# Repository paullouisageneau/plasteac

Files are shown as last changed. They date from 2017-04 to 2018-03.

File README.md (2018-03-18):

# plasteac
A 3D-printed robotic dancing teapot

Refer to each subproject for license information.

Read my blog articles for more information:

https://chapelierfou.org/blog/plasteac-a-dancing-teapot.html

https://chapelierfou.org/blog/plasteac-enhancements.html

https://vimeo.com/214493309

Plasteac

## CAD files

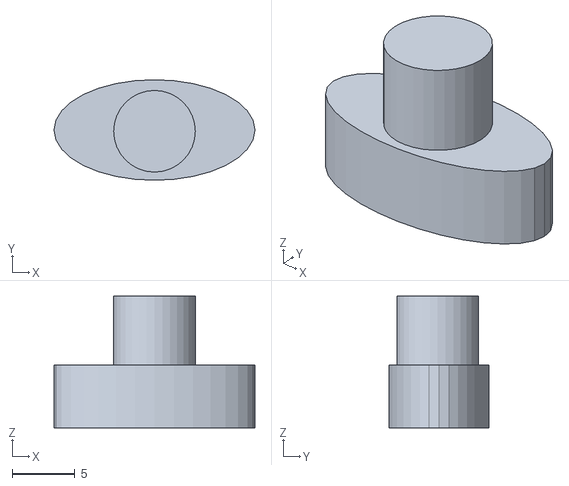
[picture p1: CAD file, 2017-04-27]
models/lid2_button.stl
16.0 x 8.00 x 10.5

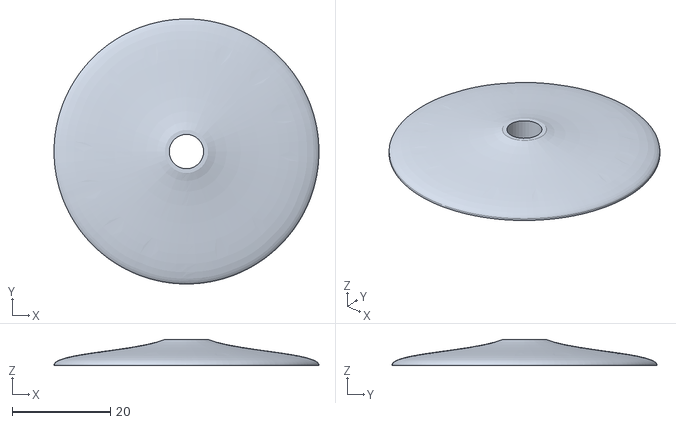
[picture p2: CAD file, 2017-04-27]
models/lid2_hole.stl
54.0 x 54.0 x 5.35

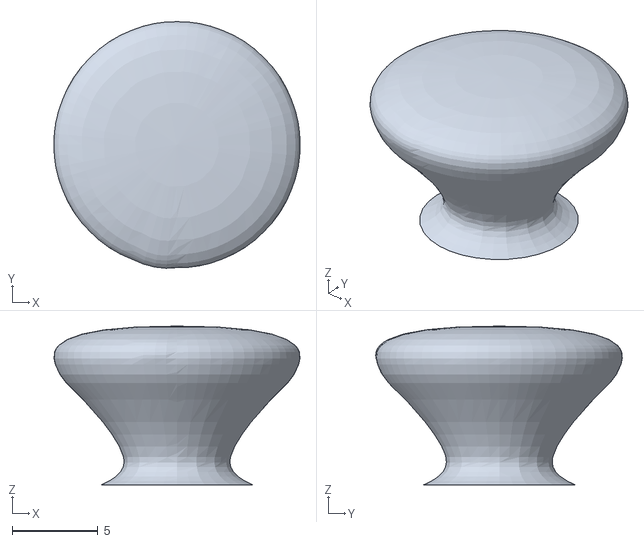
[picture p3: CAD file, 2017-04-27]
models/lid2_handle.stl
14.3 x 14.4 x 9.24

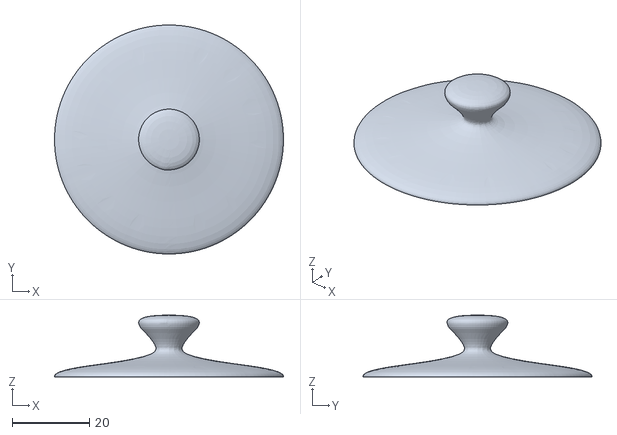
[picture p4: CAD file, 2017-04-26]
models/utah_lid.stl
59.4 x 59.4 x 16.0

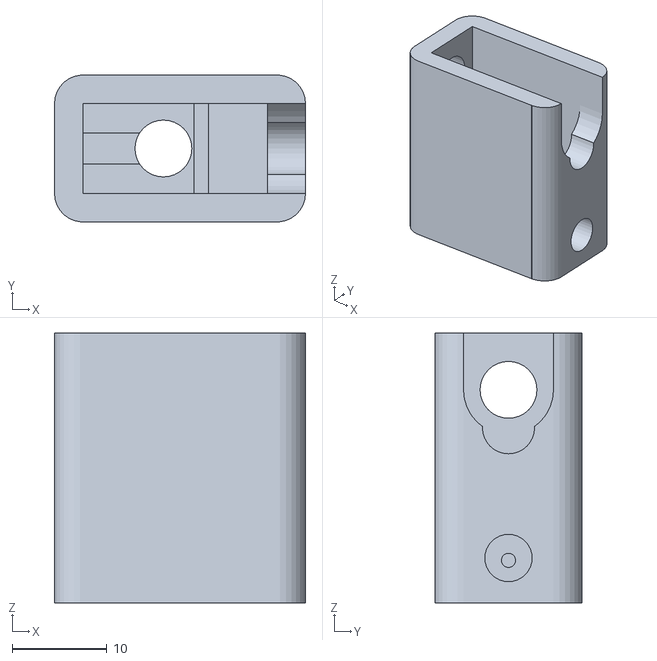
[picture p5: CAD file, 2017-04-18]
models/leg.stl
26.5 x 15.5 x 28.5

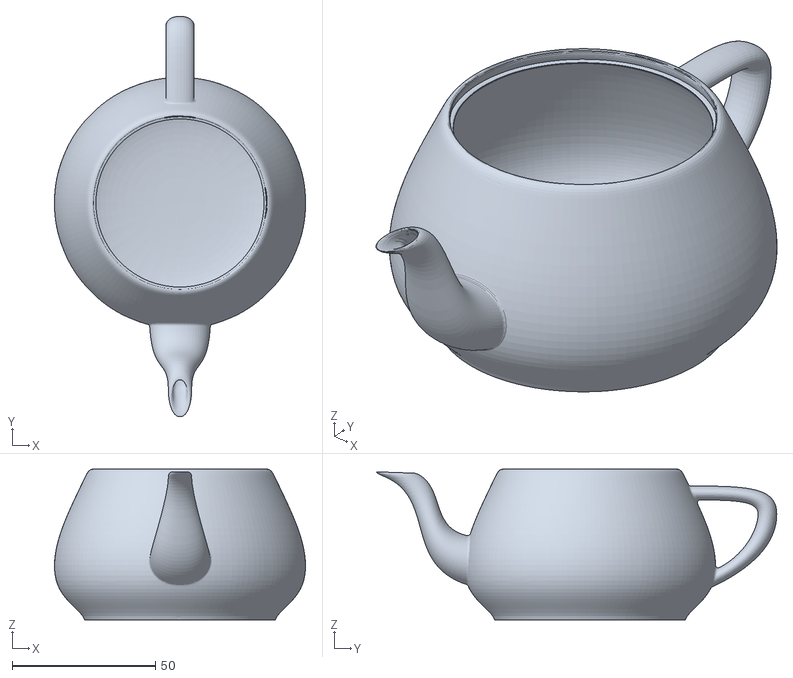
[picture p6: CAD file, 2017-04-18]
models/utah_teapot.stl
87.7 x 140.0 x 52.6

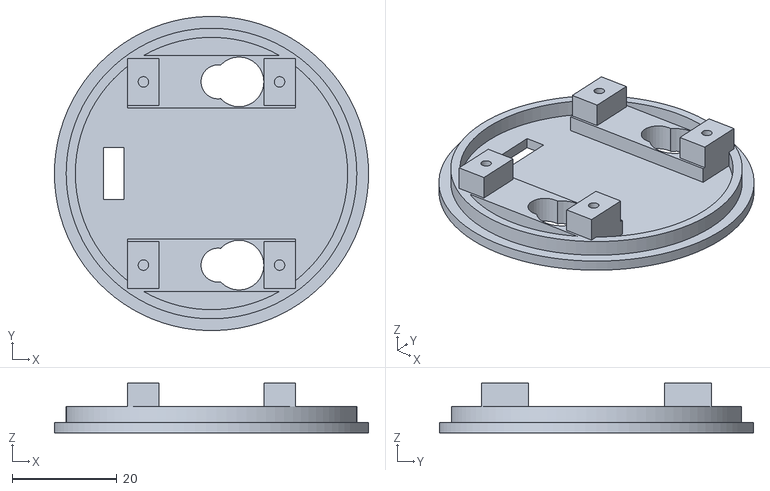
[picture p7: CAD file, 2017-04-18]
models/platform.stl
60.0 x 60.0 x 9.50

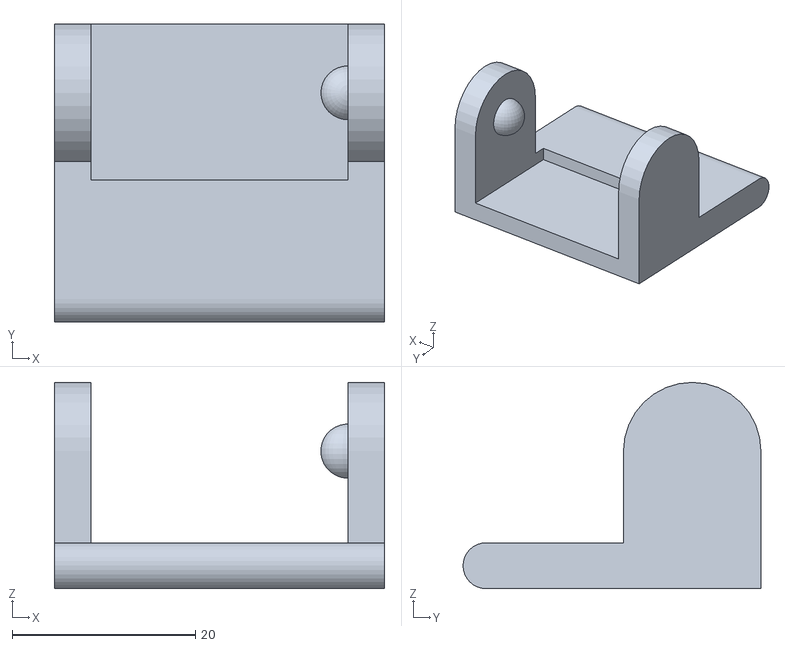
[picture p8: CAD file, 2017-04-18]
models/footr.stl
36.0 x 32.5 x 22.5

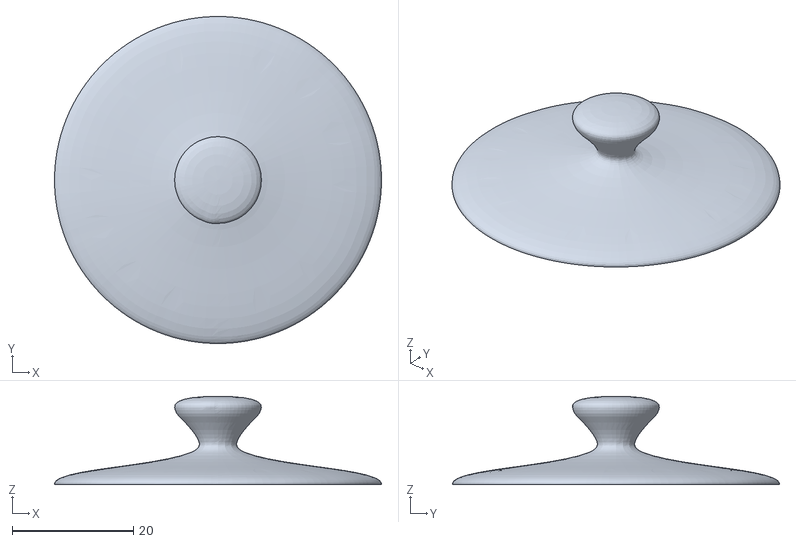
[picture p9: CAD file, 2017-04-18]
models/lid.stl
54.0 x 54.0 x 14.6

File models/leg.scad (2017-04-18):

/* 
 * Copyright (c) 2017 by Paul-Louis Ageneau
 *
 * This program is free software: you can redistribute it and/or modify
 * it under the terms of the GNU General Public License as published by
 * the Free Software Foundation, either version 3 of the License, or
 * (at your option) any later version.
 *
 * This program is distributed in the hope that it will be useful,
 * but WITHOUT ANY WARRANTY; without even the implied warranty of
 * MERCHANTABILITY or FITNESS FOR A PARTICULAR PURPOSE.  See the
 * GNU General Public License for more details.
 *
 * You should have received a copy of the GNU General Public License
 * along with this program.  If not, see <http://www.gnu.org/licenses/>.
 */

servo_height = 19 + 0.5;
servo_width  = 20 + 0.5;
servo_depth  =  9 + 0.5;
servo_side   =  6;
border = 3;
$fn = 32;

union() {
    difference() {
        rcube([servo_height, servo_depth, servo_width + servo_side] + [border*2+1, border*2, 2], border);
        translate([-0.5, 0, 2]) union() {
            cube([servo_height, servo_depth, servo_width + servo_side], center = true);
            translate([-servo_height/4, 0, 3-servo_width/2- 6]) cube([servo_height/2, 3.25, 3], center = true);
            translate([-1.25, 0, -servo_width/2]) cylinder(r = 3, h = 20, center = true);
            translate([0, 0, servo_width/2 - 4]) {
                translate([border+0.01, 0, servo_width/2]) cube([servo_height+border*2, servo_depth, servo_width], center = true);
                translate([servo_height/2, 0, -4]) rotate([0, 90, 0]) cylinder(r = 2.75, h = 10, center = true);
                translate([0, 0, 0]) rotate([0, 90, 0]) cylinder(r = 3, h = servo_height*2, center = true);
                translate([servo_height/2, 0, 0]) rotate([0, 90, 0]) cylinder(r = servo_depth/2, h = 10, center = true);
                translate([servo_height/2, 0, -18]) union() {
                    translate([0, 0, 0.25]) rotate([0, 90, 0]) cylinder(r = 2.5, h = 10, center = true);
                    translate([-3.75, 0, 0]) cube([7.5, servo_depth, servo_side], center = true);
                }
            }
        }
    }
    translate([servo_height/2-7.5, 0, 8 - 18]) difference() {
        cube([1.5, servo_depth, servo_side], center = true);
        translate([0, 0, 0.25]) rotate([0, 90, 0]) cylinder(r = 0.75, h = 10, center = true);
    }
}

module rcube(size, border) {
    union() {
        $fn = 30;
        cube(size = size - [0, border, 0]*2, center = true);
        cube(size = size - [border, 0, 0]*2, center = true);
        v = [size.x/2-border, size.y/2-border, size.z/2];
        translate([ v.x, v.y, 0]) cylinder(r = border, h = v.z*2, center = true);
        translate([ v.x,-v.y, 0]) cylinder(r = border, h = v.z*2, center = true);
        translate([-v.x, v.y, 0]) cylinder(r = border, h = v.z*2, center = true);
        translate([-v.x,-v.y, 0]) cylinder(r = border, h = v.z*2, center = true);
    }
}

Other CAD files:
models/footl.stl
models/footl.scad
models/footr.scad
models/lid.scad
models/lid2_button.scad
models/lid2_handle.scad
models/lid2_hole.scad
models/platform.scad
models/top.scad

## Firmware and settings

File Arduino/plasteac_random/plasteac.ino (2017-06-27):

/* 
 * Copyright (c) 2017 by Paul-Louis Ageneau
 * This file is part of Plasteac
 *
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
 * You should have received a copy of the GNU General Public License
 * along with this program.  If not, see <http://www.gnu.org/licenses/>.
 */

// ---------- Pin setup ----------
const int servoPins[4] = {5, 6, 7, 8};
const int speakerPin = 3;	// connected to a piezzo speaker

// -------- Servo offsets --------
const int leftHipOffset  = 5;
const int rightHipOffset = 5;
const int leftFootOffset  = 5;
const int rightFootOffset = 5;

//const char *melody = "4C42D44E42F46G46C56A46C56G46R06F44F42G46E46E46D44D42E46C46R07C52A44G42G46F46E46D46C46R0"; // I'm a little teapot
const char *melody = "4E52B42C54D52C52B44A42A42C54E52D52C56B42C54D54E54C54A42A42A42B42C56D52F54A52G52F56E52C54E52D52C54B42B42C54D54E54C54A44A44R0"; // Tetris

#include "move.h"
#include "player.h"

Player player(speakerPin);
long bpm = 120L;

void sync()
{
  // Given set BPM, delay until the next quarter of a beat
  static unsigned long lastMillis = 0;
  unsigned long duration = 60000L/(bpm*4);
  long leftMillis = lastMillis + duration - millis();
  if(leftMillis > 0) delay(leftMillis);
  lastMillis = millis();
  
  // Update player
  player.sync(bpm);
}

void setup()
{
  // Init serial
  Serial.begin(9600);

  // Init legs
  initialize();

  // Seed random generator
  randomSeed(analogRead(0));

  delay(4000);

  // Play melody
  if(melody) player.play(melody, true);
  
  stand_rythm(2);
}

void loop() 
{
  // Random dance
  switch(random(8))
  {
    case 0:
    case 1:
      stand_rythm(2+random(4));
      break;
      
    case 2:
      side_left(2+random(4));
      break;

    case 3:
      side_right(2+random(4));
      break;
      
    case 4:
      hello_left(1+random(4));
      break;
      
    case 5:
      hello_right(1+random(4));
      break;

    case 6:
    case 7:
      walk(1+random(1));
      break;
  }
}

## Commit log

2017-04-18 Added models
    [footl.scad, footl.stl, footr.scad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]
2017-04-18 Added Arduino program
2017-04-18 Changed servo pins
2017-04-19 Fixed servo direction
2017-04-21 Upgraded control flow in syncMelody()
2017-04-21 Fixed control flow in syncMelody()
2017-04-26 Fixed utah_lid model
    [utah_lid.stl]
2017-04-27 Added new lid with integrated switch
    [lid2_button.scad, lid2_button.stl, lid2_handle.scad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]
2017-06-07 Speaker pin passed in Player constructor
